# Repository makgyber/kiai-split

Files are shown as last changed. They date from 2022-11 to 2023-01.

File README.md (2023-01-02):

# Kiai Wireless Split Keyboard

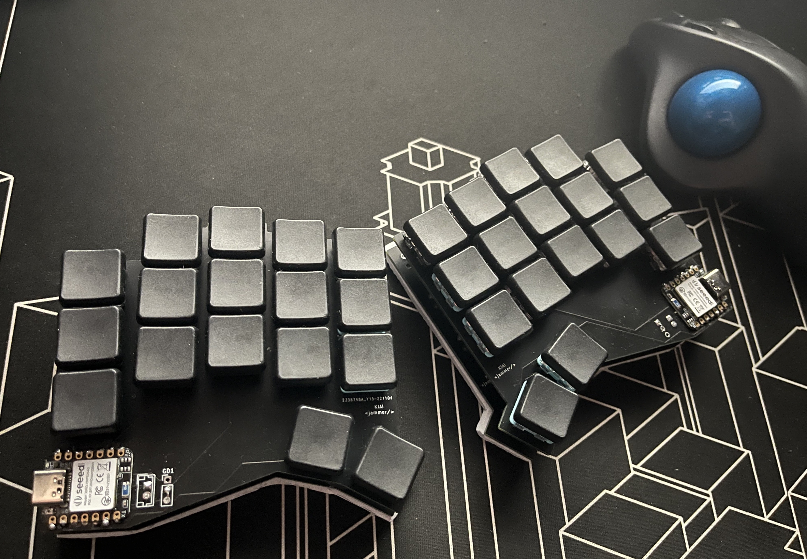
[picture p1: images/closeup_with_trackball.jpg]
with trackball setup

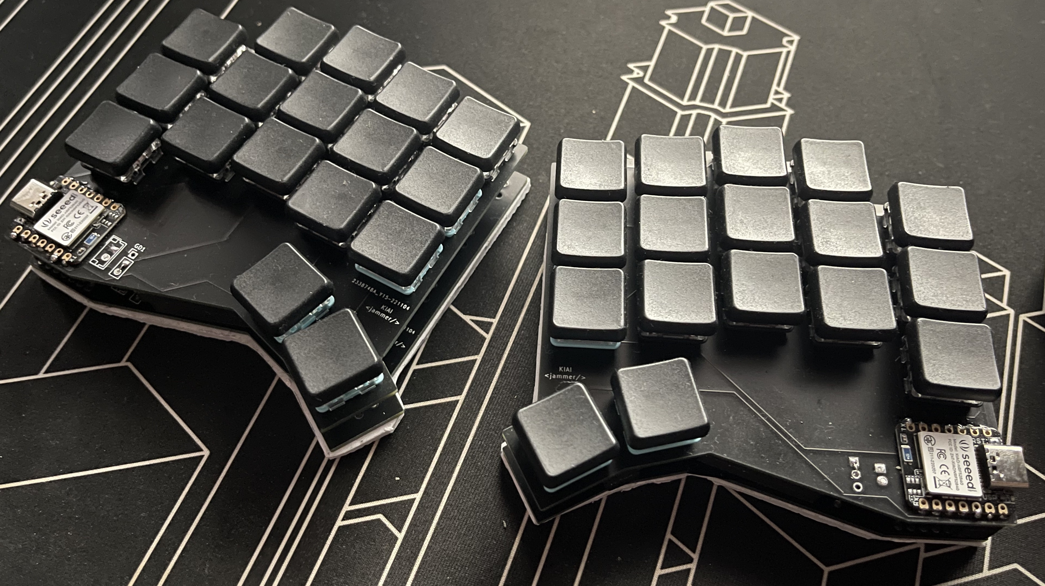
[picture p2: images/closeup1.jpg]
angled board view

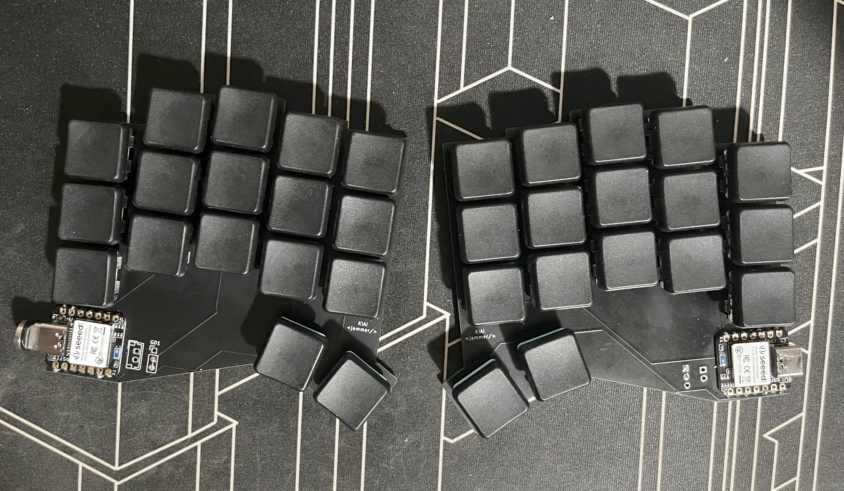
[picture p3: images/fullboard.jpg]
full board view

## Features
- Seeed Studio XIAO nRF52840 
- ZMK
- 34-keys 
- low profile Choc v1

## Requirements
- Seeed Studio XIAO nRF52840 (2)
- Choc v1 switche (34)
- 1N4148 SOD-123  (34)
- 2 pcbs (gerbers and kicad files shared in this repo)
- 3.7v lipo batteries (2)

## Build Notes
Because I wanted to have the xiao modules both facing up so the built-in reset button on the xiao is readily accessible, there are a couple of things that may be different from how other boards are normally set up.

For the left hand side, need to jumper the bottom two holes as shown below:

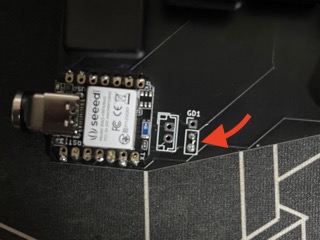
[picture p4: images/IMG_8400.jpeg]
left board jumper close up


The right side will also need the jumper but on the upper two holes instead:

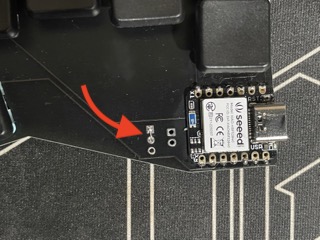
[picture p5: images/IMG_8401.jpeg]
right board jumper close up


The diodes should mirror the orientation on the opposite board.

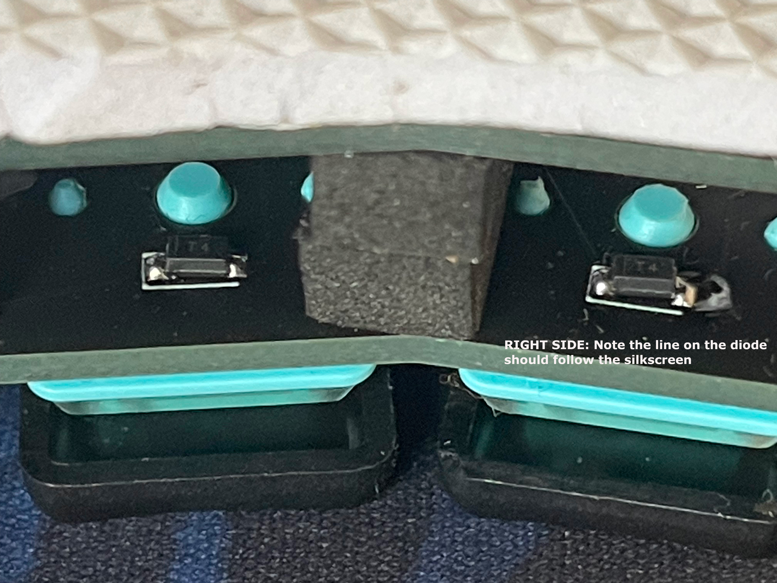
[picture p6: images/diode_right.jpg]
right hand diode orientation


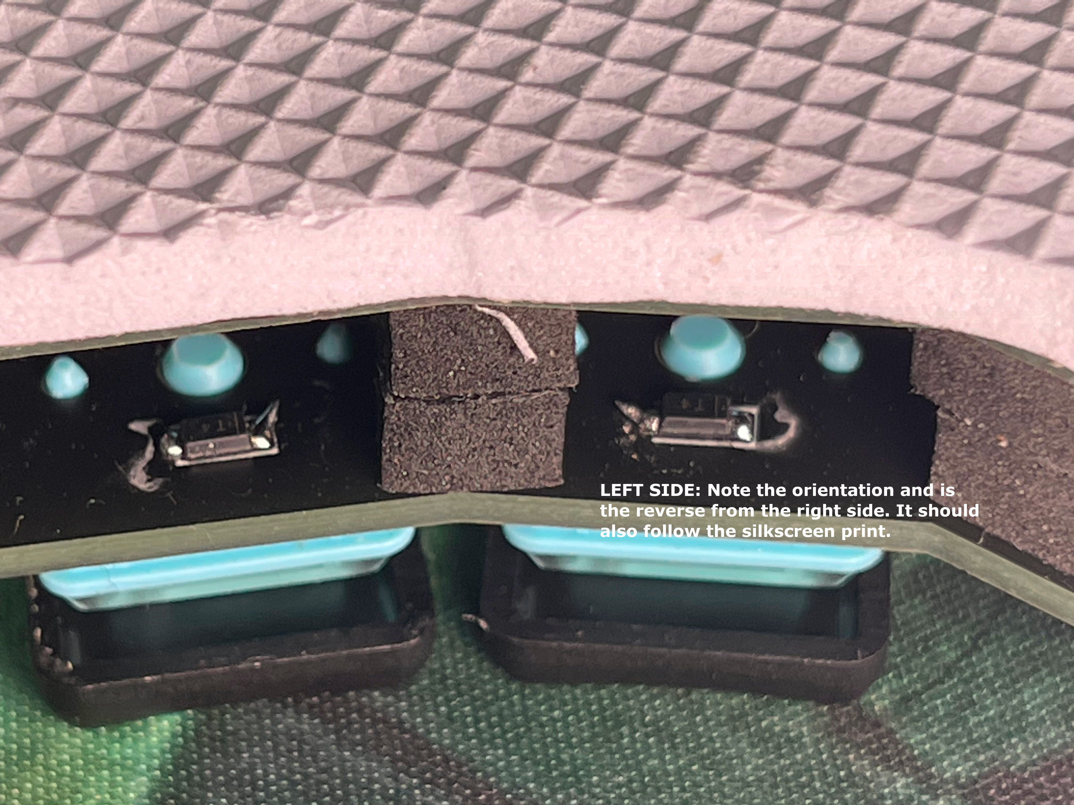
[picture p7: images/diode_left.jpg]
left hand diode orientation


## Flashing the Firmware
For convenience, the compiled uf2 files are in the bin folder. 
`left.uf2` -> for the left side
`right.uf2` -> for the right side
`reset.uf2` -> can be flashed to both boards to reset. I found this useful when the slave side is not pairing with the master side.

### How to upload the firmware to your board:
- Connect one keyboard to your computer via USB 
- Double-click the reset button on the xiao module on the left board. When the XIAO-SENSE folder appears, copy over `left.uf2` onto that folder. It will automatically eject after.
- Do the same to the right keyboard, this time flashing the `right.uf2` file.
- TIP: immediately after flashing try to put the keyboard into bootloader mode. This prevents it from trying to pair before you are ready. Re-activate the two sides at the same time; this usually helps when you find the slave side does not register keystrokes. 

## Building/Compiling your own firmware

- install ZMK following this guide: [ZMK Basic Setup](https://zmk.dev/docs/development/setup) 
- in your `{zmk-dir}/app/board/shields` directory, create a folder named `kiai`
- copy the files in the `zmk` folder in this repo into your new `kiai` directory
- compile the hex file for your left board using 
  
  ```west build -p -b seeeduino_xiai_ble -d build/kiai/left -- -DSHIELD=kiai_left```
- this will create a `zmk.uf2` file in `{zmk-dir}/app/build/kiai/left/zephyr`
- use this file to flash the left-side board
- compile the hex file for your right-side board using
  
  ```west build -p -b seeeduino_xiai_ble -d build/kiai/right -- -DSHIELD=kiai_right```

- this will create a `zmk.uf2` file in `{zmk-dir}/app/build/kiai/right/zephyr`
- use this file to flash the right-side board

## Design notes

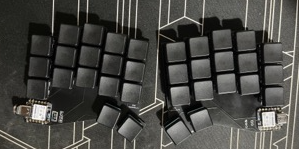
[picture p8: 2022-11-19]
images/fullboard.jpg.png

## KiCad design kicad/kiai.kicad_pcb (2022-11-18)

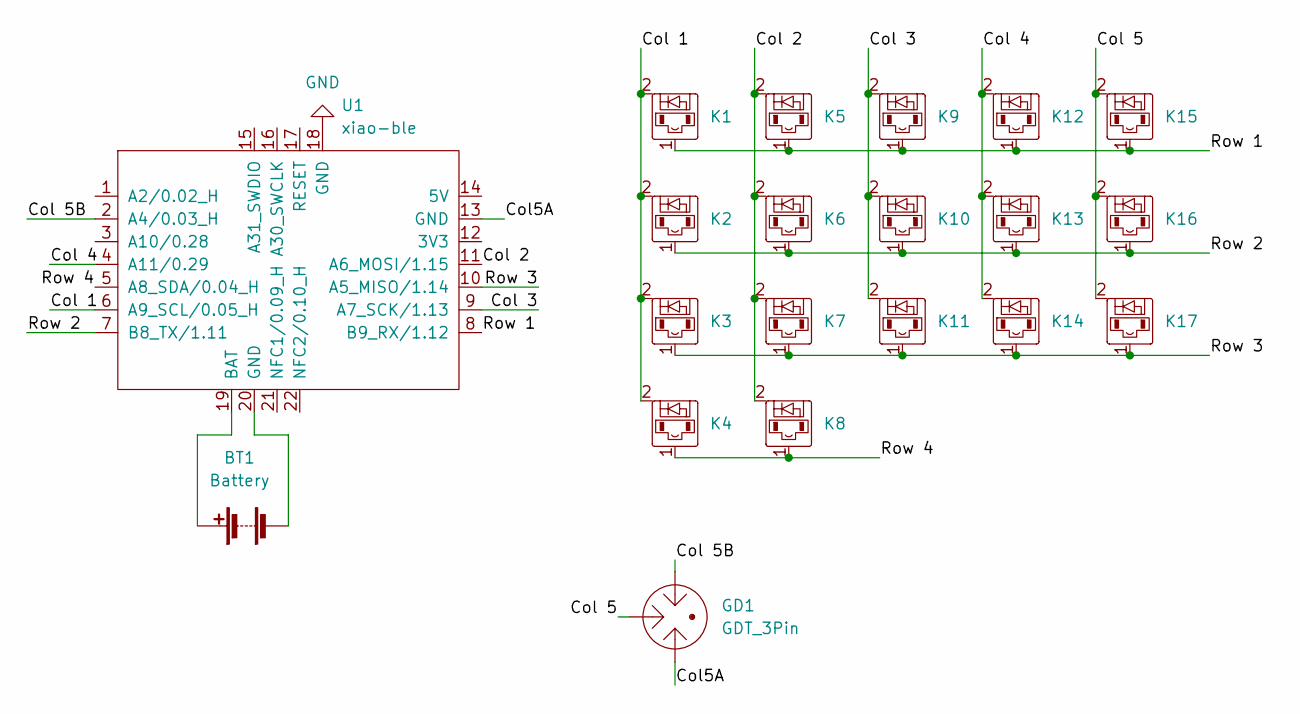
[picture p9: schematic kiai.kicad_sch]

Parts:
BT1: Battery; JST_EH_B2B-EH-A_1x02_P2.50mm_Vertical
GD1: GDT_3Pin; PinHeader_1x03_P1.00mm_Vertical
K1, K2, K3, K4, K5, K6, K7, K8, K9, K10, K11, K12, K13, K14, K15, K16, K17: diode-choc; pg1350-DR
U1: xiao-ble; xiao-ble-tht

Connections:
/Col5A: GD1.1, U1.13 (GND)
/Col 1: K1.2, K2.2, K3.2, K4.2, U1.6 (A9_SCL/0.05_H)
/Col 2: K5.2, K6.2, K7.2, K8.2, U1.11 (A6_MOSI/1.15)
/Col 3: K9.2, K10.2, K11.2, U1.9 (A7_SCK/1.13)
/Col 4: K12.2, K13.2, K14.2, U1.4 (A11/0.29)
/Col 5: GD1.2, K15.2, K16.2, K17.2
/Col 5B: GD1.3, U1.2 (A4/0.03_H)
/Row 1: K1.1, K5.1, K9.1, K12.1, K15.1, U1.8 (B9_RX/1.12)
/Row 2: K2.1, K6.1, K10.1, K13.1, K16.1, U1.7 (B8_TX/1.11)
/Row 3: K3.1, K7.1, K11.1, K14.1, K17.1, U1.10 (A5_MISO/1.14)
/Row 4: K4.1, K8.1, U1.5 (A8_SDA/0.04_H)
GND: U1.18 (GND)
unnamed: BT1.1 (+), U1.19 (BAT)
unnamed: BT1.2 (-), U1.20 (GND)

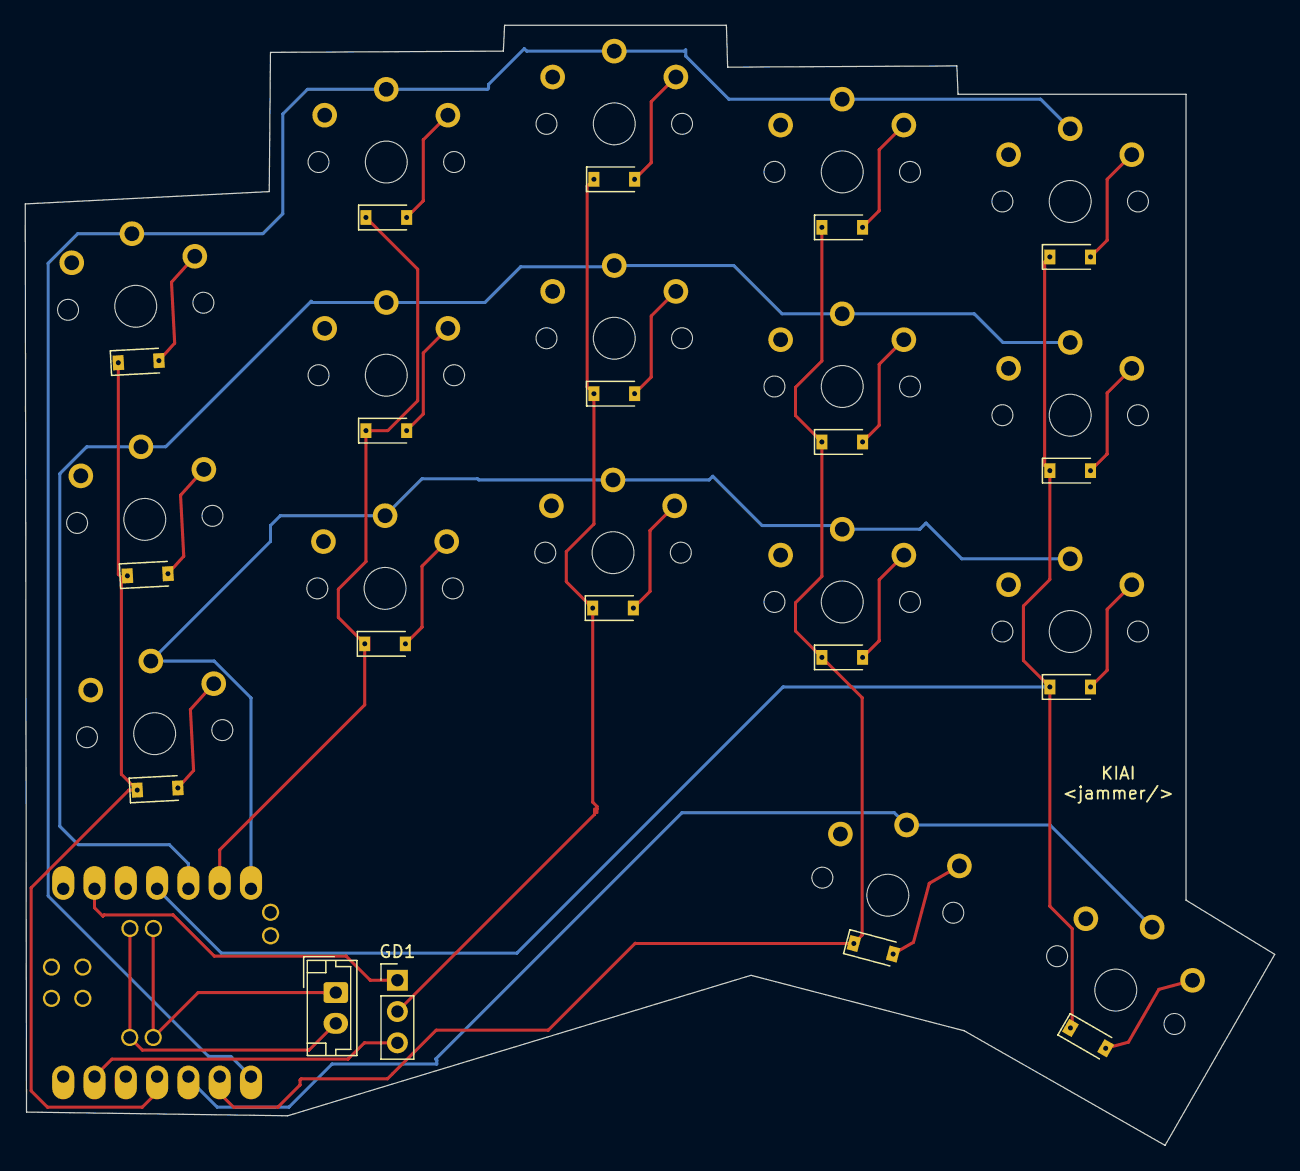
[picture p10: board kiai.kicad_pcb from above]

Board: 2 copper layers, 101.4 x 90.9 mm, 20 parts (0 on the bottom side), 13 nets.

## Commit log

2022-11-25 update board image
2023-01-02 update readme with diode orientation pics
